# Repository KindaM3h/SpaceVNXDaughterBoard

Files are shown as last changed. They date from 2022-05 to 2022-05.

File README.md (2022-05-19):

# SpaceVNXDaughterBoard
- Direct RF Sampling concept for SDR applications.
- Generated PCB (Schematic, BOM, Layout, 3D...) information is [here](SpaceVNXDaughterBoard.pdf).
- Pod compilant with [SYZYGY](https://syzygyfpga.io/specification/) TXR-4 tranceiver peripheral specification.
- JESD204B Links to [ADC](https://www.ti.com/product/ADC12DJ800-Q1) and [DAC](https://www.ti.com/product/DAC37J82). 
- Clock Syntethizer and required power LDO's onboard.
- 2 Tx and 2 Rx RF paths with [MMCX](https://www.samtec.com/products/mmcx-sm) connectors.
- Rx RF path includes option to solder matching network (0402 footprints).
- Both Tx and Rx path include footprints for LTCC filters in Mini-Circuits [FV1206](https://www.minicircuits.com/pcb/98-pl137.pdf).

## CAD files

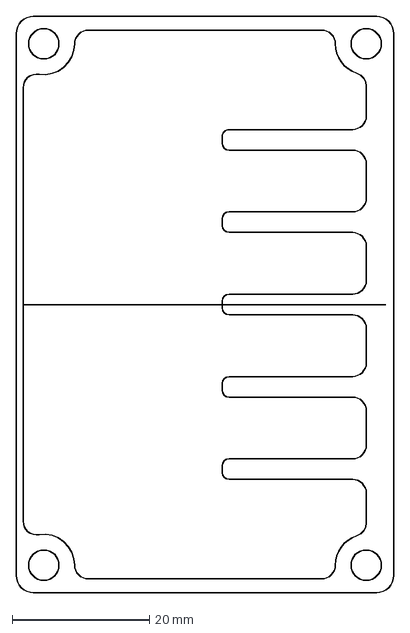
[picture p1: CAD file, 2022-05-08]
MCAD/Outline/Mezzanine.dxf
55.0 x 84.0 mm

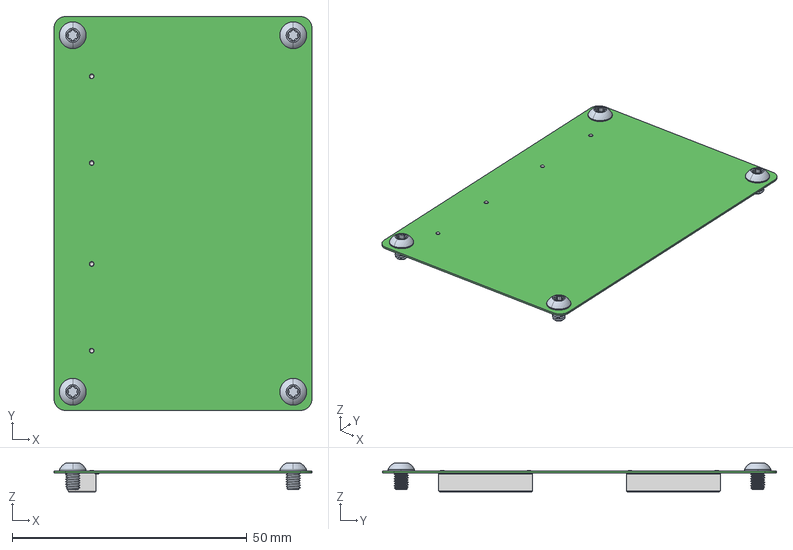
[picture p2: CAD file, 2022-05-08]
MCAD/SpaceVNXDaughterBoard.step
55.0 x 84.0 x 6.18 mm
_TQTH-020-01-F-D-DP-A_terminal x 2
_T-1S39-01(-020-01-D-DP)_pin x 2
_T-1G1-01_imp x 2
90910A572 x 4

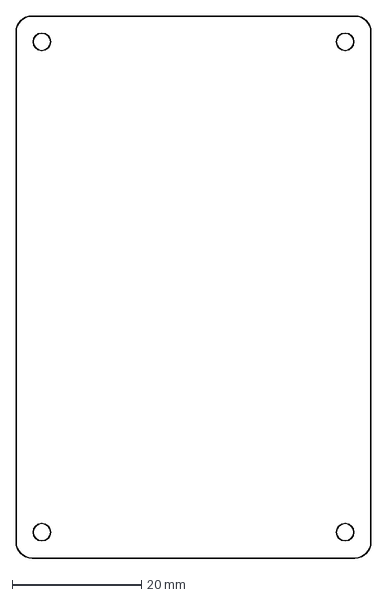
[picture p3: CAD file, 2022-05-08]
MCAD/Outline/Vita74_SpaceVNX_DaughterCard.dxf
55.0 x 84.0 mm

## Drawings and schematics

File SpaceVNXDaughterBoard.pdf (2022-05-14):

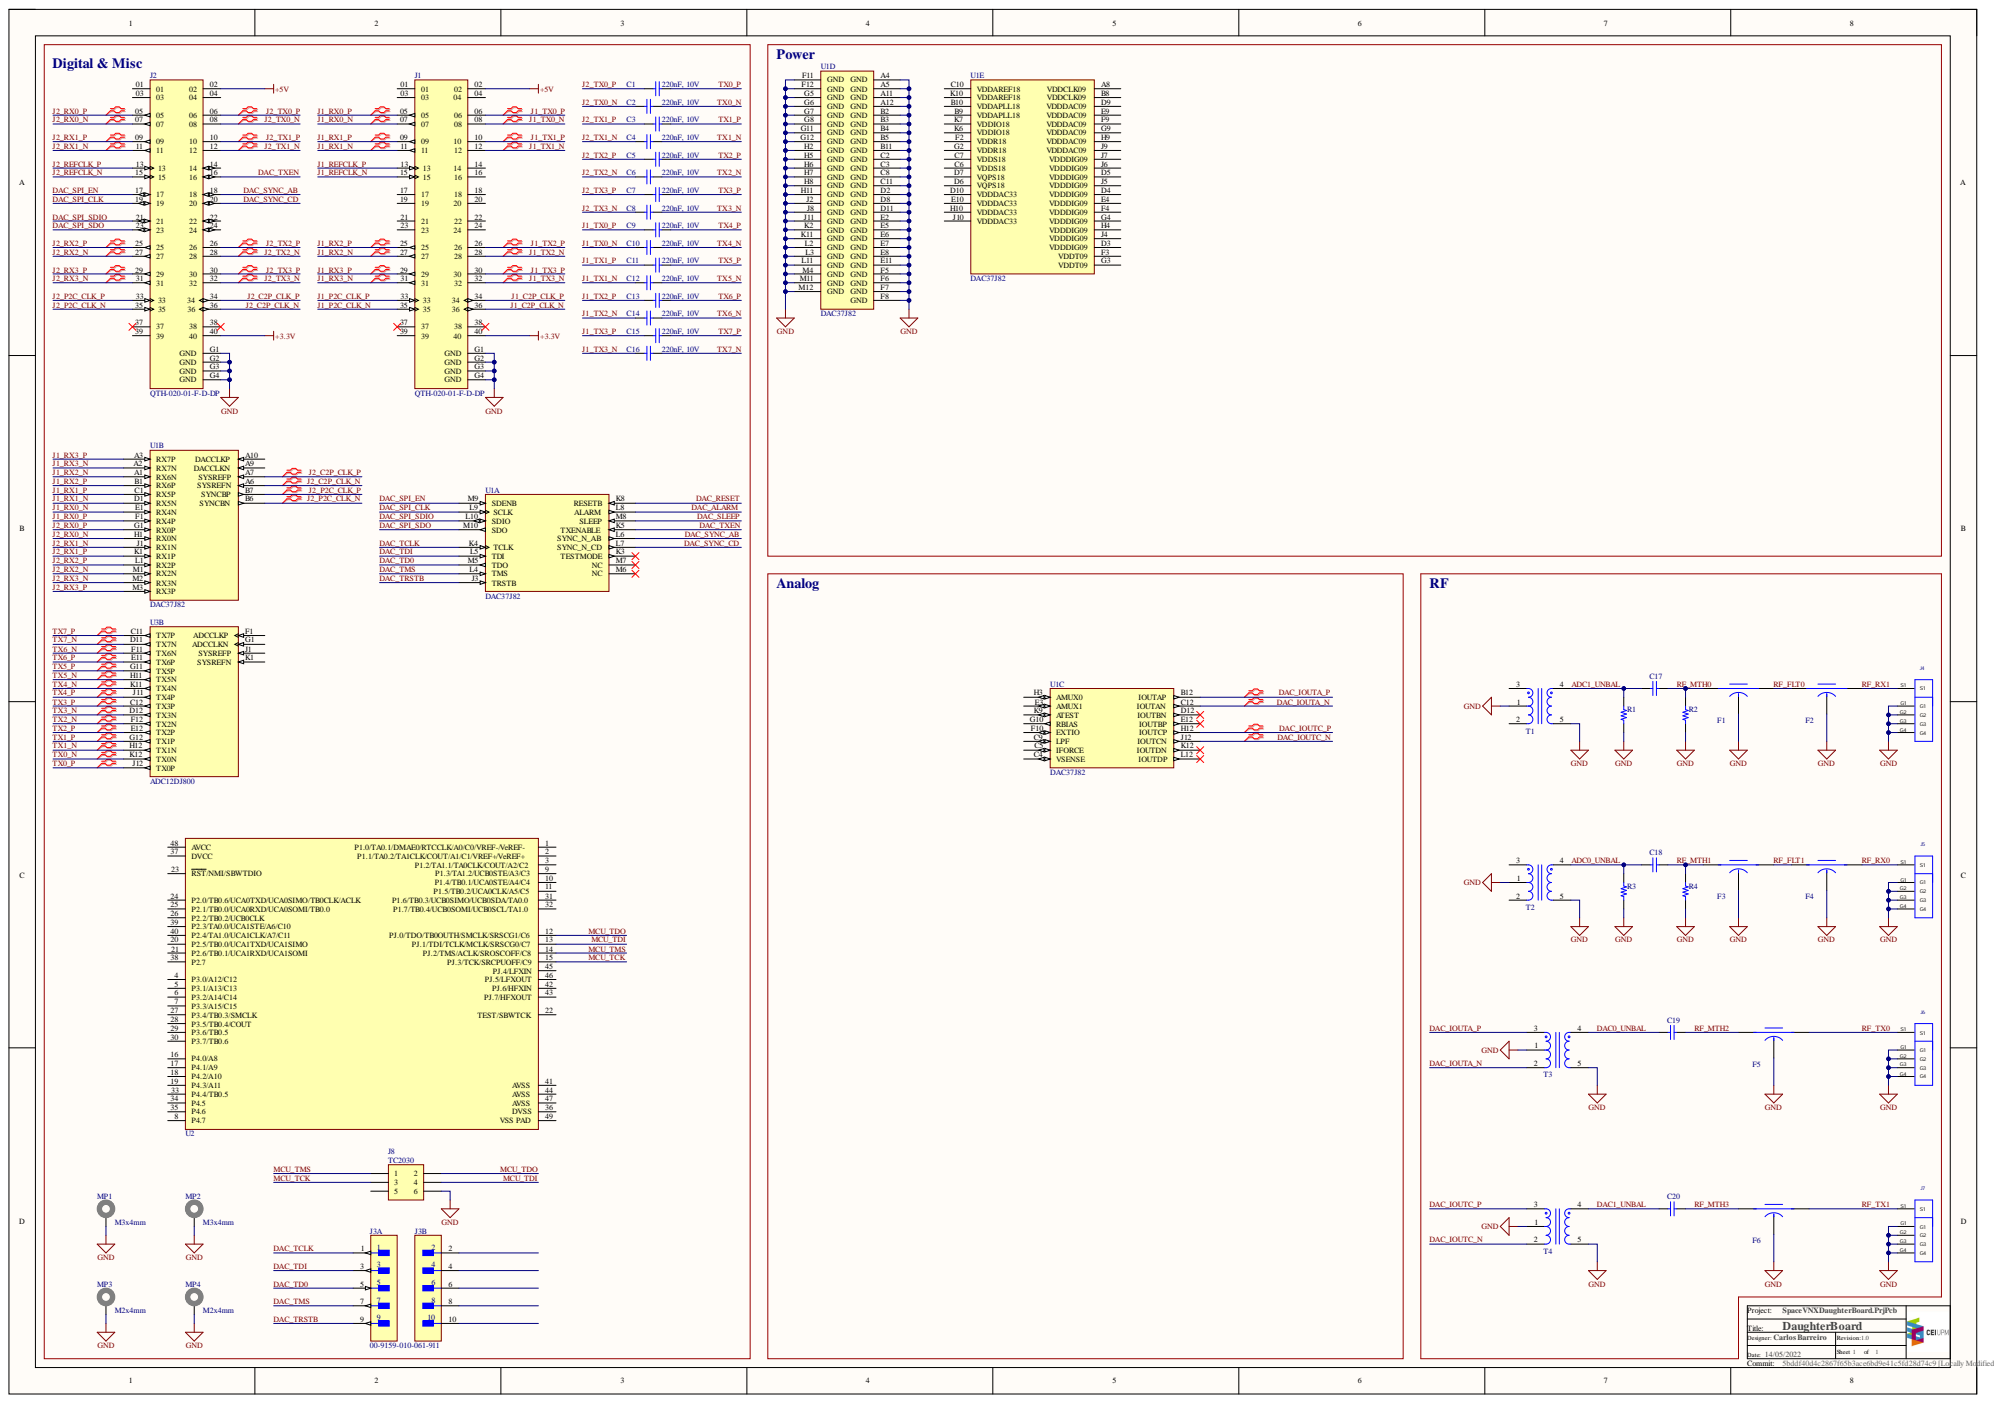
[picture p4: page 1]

Designer: CarlosBarreiro | Revision:1.0

Date: 14/05/2022 | Sheet 1 of 1

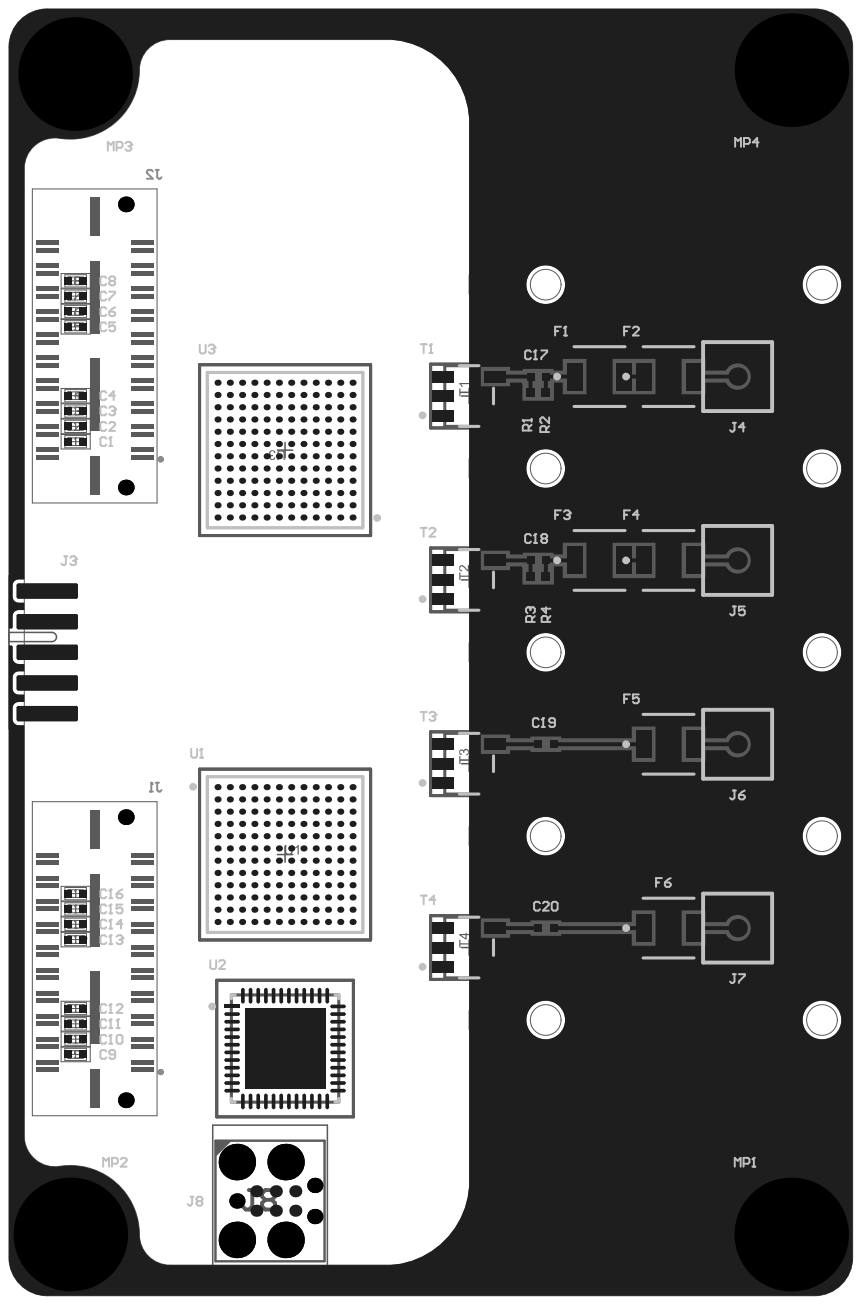
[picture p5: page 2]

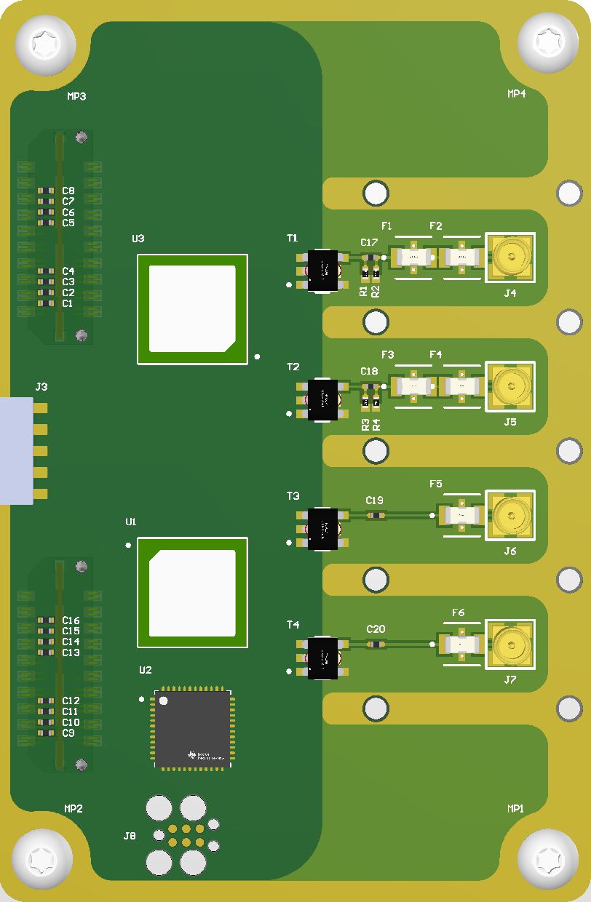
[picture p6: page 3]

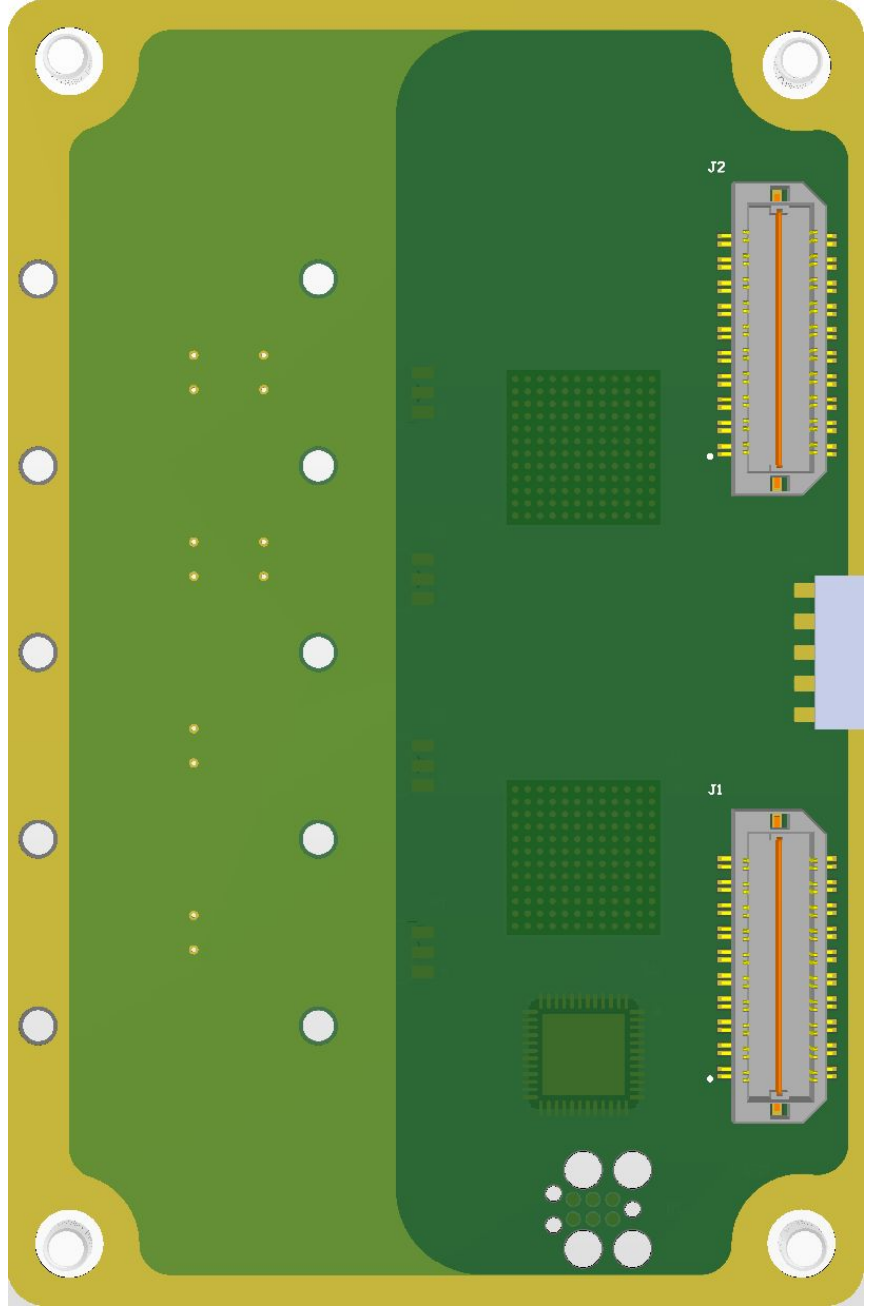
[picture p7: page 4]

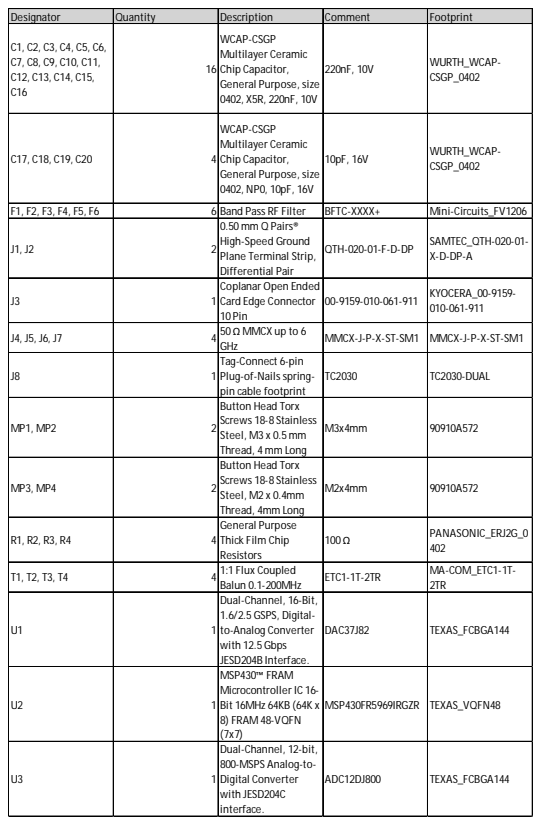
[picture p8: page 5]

Designator | Quantity | Description | Comment | Footprint

C1, C2, C3, C4, C5, C6, C7, C8, C9, C10, C11, C12, C13, C14, C15, C16 | 16 | WCAP-CSGP Multilayer Ceramic Chip Capacitor, General Purpose, size 0402, X5R, 220nF, 10V | 220nF, 10V | WURTH_WCAP-CSGP_0402

C17, C18, C19, C20 | 4 | WCAP-CSGP Multilayer Ceramic Chip Capacitor, General Purpose, size 0402, NP0, 10pF, 16V | 10pF, 16V | WURTH_WCAP-CSGP_0402

F1, F2, F3, F4, F5, F6 | 6 Band Pass RF Filter | | BFTC-XXXX+ | Mini-Circuits_FV1206
J1, J2 | 2 | 0.50mm Q Pairs® High-Speed Ground Plane Terminal Strip, Differential Pair | QTH-020-01-F-D-DP | SAMTEC_QTH-020-01-X-D-DP-A

J3 | 1 | Coplanar Open Ended Card Edge Connector 10 Pin | 00-9159-010-061-911 | KYOCERA_00-9159-010-061-911

J4, J5, J6, J7 | 4 50Ω MMCX up to 6 | GHz | MMCX-J-P-X-ST-SM1 | MMCX-J-P-X-ST-SM1

J8 | 1 | Tag-Connect 6-pin Plug-of-Nails spring-pin cable footprint | TC2030 | TC2030-DUAL

MP1, MP2 | 2 | Button Head Torx Screws 18-8 Stainless Steel, M3 x 0.5mm Thread, 4mm Long | M3x4mm | 90910A572

MP3, MP4 | 2 | Button Head Torx Screws 18-8 Stainless Steel, M2 x 0.4mm Thread, 4mm Long | M2x4mm | 90910A572

R1, R2, R3, R4 | 4 | General Purpose Thick Film Chip Resistors | 100Ω | PANASONIC_ERJ2G_0 402

T1, T2, T3, T4 | 4 1:1 Flux Coupled | Balun 0.1-200MHz | ETC1-1T-2TR | MA-COM_ETC1-1T-2TR

U1 | 1 | Dual-Channel, 16-Bit, 1.6/2.5 GSPS, Digital-to-Analog Converter with 12.5 Gbps JESD204B Interface. | DAC37J82 | TEXAS_FCBGA144

U2 | 1 | MSP430™ FRAM Microcontroller IC 16-Bit 16MHz 64KB (64K x 8) FRAM 48-VQFN (7x7) | MSP430FR5969IRGZR | TEXAS_VQFN48

U3 | 1 | Dual-Channel, 12-bit, 800-MSPS Analog-to-Digital Converter with JESD204C interface. | ADC12DJ800 | TEXAS_FCBGA144

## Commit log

2022-05-08 Added SpaceVNXDaughterBoard as submodule
    [Mezzanine.dxf, SpaceVNXDaughterBoard.PcbDoc, SpaceVNXDaughterBoard.PrjPcb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]
2022-05-08 Schematic WIP
    [SpaceVNXDaughterBoard.SchDoc]
2022-05-08 Advances in Schematic
    [SpaceVNXDaughterBoard.PrjPcb, SpaceVNXDaughterBoard.SchDoc]
2022-05-11 Commit all RF parts finished, ready to simulate in HFSS. Needs ADC yet and digital/analog routing
    [SpaceVNXDaughterBoard.PcbDoc, SpaceVNXDaughterBoard.PrjPcb, SpaceVNXDaughterBoard.SchDoc]
2022-05-14 Update SpaceVNXDaughterBoard
    [SpaceVNXDaughterBoard.PcbDoc, SpaceVNXDaughterBoard.PrjPcb, SpaceVNXDaughterBoard.SchDoc]
2022-05-14 Added ADC
    [SpaceVNXDaughterBoard.PcbDoc, SpaceVNXDaughterBoard.PrjPcb, SpaceVNXDaughterBoard.SchDoc]
2022-05-14 ADC Power
    [SpaceVNXDaughterBoard.PcbDoc, SpaceVNXDaughterBoard.PrjPcb, SpaceVNXDaughterBoard.SchDoc]
2022-05-18 Final stackup based on JLCPCB 4layer-1oz-jlc2313-1.0mm, re-traced with new impedance profiles on D100 and SE50
    [SpaceVNXDaughterBoard.PcbDoc]
2022-05-18 Finished PDN filtering on ADC and device side decoupling
    [SpaceVNXDaughterBoard.PcbDoc]
2022-05-21 Progress on DAC PDN Network
    [SpaceVNXDaughterBoard.PcbDoc, SpaceVNXDaughterBoard.SchDoc]
2022-05-21 Update generated outputs
    [SpaceVNXDaughterBoard.PcbDoc]
